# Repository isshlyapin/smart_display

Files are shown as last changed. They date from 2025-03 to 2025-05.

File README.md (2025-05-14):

# Ретрофутуристический дисплей

**Год реализации**: 2025  
**Авторы**:  
- Шляпин Илья (Б01-307) 
- Уткин Павел (Б01-307)

## Описание проекта

Проект представляет собой компактный LED-дисплей с микроконтроллером ESP32, выполненный в стиле ретрофутуризма. Устройство отображает полезную информацию (время, температура и др.), подключается по Wi-Fi и Bluetooth, поддерживает настройку яркости, цветовой гаммы и шаблонов.

Основная цель проекта — снизить информационную перегрузку пользователя, предоставляя важные данные без использования телефона или компьютера.

## Используемые компоненты

- LED матрица 64×32
- Микроконтроллер ESP32
- Датчик температуры и влажности (например, DHT11/22 или аналог)
- Блок питания (адаптер или трансформатор)
- Печатная плата (самодельная, фрезерованная)
- 3D-печатный корпус

## Технологии и инструменты

- Arduino (прошивка ESP32)
- КОМПАС-3D (проектирование корпуса)
- 3D-принтер
- GitHub (хранение кода и макетов)
- C++ (при необходимости визуализации/обработки)
- QR-код генератор для GitHub-ссылки

## Установка и запуск

1. Склонируйте репозиторий:
   ```bash
   git clone https://github.com/your_username/smart_display.git
   ```
2. Загрузите прошивку на ESP32 через Arduino IDE.
3. Подключите устройство к Wi-Fi
4. Дисплей автоматически начнет отображение.

## Сборка устройства

Для правильного подключения LED-матрицы 64×32 к микроконтроллеру ESP32, используйте следующие GPIO пины на плате:

- **GPIO 22** — Красный верхний (R1)
- **GPIO 23** — Зелёный верхний (G1)
- **GPIO 21** — Синий верхний (B1)
- **GPIO 19** — Красный нижний (R2)
- **GPIO 18** — Зелёный нижний (G2)
- **GPIO 26** — Синий нижний (B2)

Адресные линии:
- **GPIO 25** — Линия A
- **GPIO 17** — Линия B
- **GPIO 33** — Линия C
- **GPIO 16** — Линия D
- **GPIO -1** — Линия E (не используется в 64×32 панелях, только для 64×64 панелей)

Дополнительные пины для управления:
- **GPIO 4** — Latch
- **GPIO 14** — Output Enable (OE)
- **GPIO 32** — Clock (CLK)

Эти пины нужно использовать при подключении LED-матрицы к ESP32. Убедитесь, что все соединения выполнены правильно перед загрузкой прошивки.

- Спаяйте все элементы на фрезерованной плате.
- Распечатайте корпус и соберите устройство.
- Поместите все внутрь корпуса и подключите питание.

## 3D-модели

Файлы для 3D-печати (корпус, крышка) находятся в папке [`models/`](./models).  

## Функционал

- Отображение:
  - Время, дата
  - Температура и влажность
  - Пользовательские шаблоны
- Поддержка:
  - Wi-Fi, Bluetooth
  - Изменение цветовой темы
  - Настройка яркости
  - Смена часового пояса
- Расширяемость:
  - Открытый код для добавления собственных шаблонов

<video src="https://github.com/user-attachments/assets/2ec28b51-bb7a-4958-b808-4877aee1a16a" width="480px"> 
</video>

## Результаты тестирования

- Работа устройства стабильна в течение 24+ часов
- Все функции работают корректно

## QR-код на репозиторий



---

## Структура репозитория

```
smart_display/
│
├── firmware/           # Прошивка ESP32 
├── models/             # 3D-модели корпуса
├── README.md
```

---

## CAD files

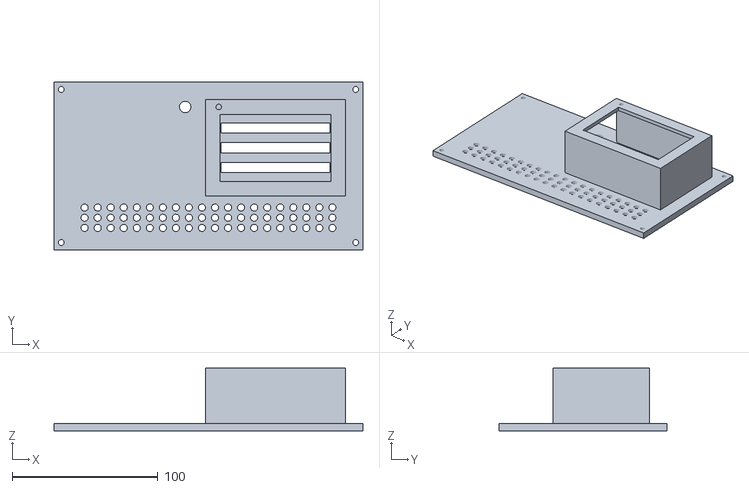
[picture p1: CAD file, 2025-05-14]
models/back_desk_smart_display.stl
212.0 x 115.0 x 43.0

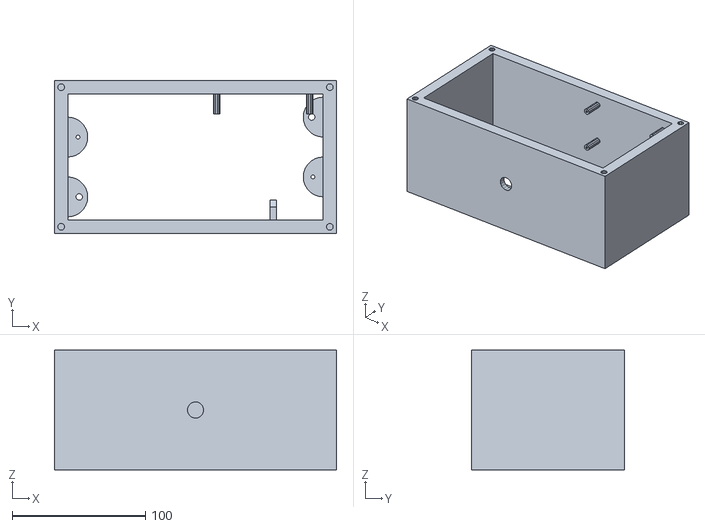
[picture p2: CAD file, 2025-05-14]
models/box_smart_display.stl
212.0 x 115.0 x 90.0

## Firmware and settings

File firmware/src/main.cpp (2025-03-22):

#include <Arduino.h>
#include <ESP32-HUB75-MatrixPanel-I2S-DMA.h>

#include "config.h"
#include "wifi_controller.h"
#include "bluetooth_controller.h"
#include "temperature_controller.h"
#include "time_controller.h"
#include "display.h"

DisplayController& displayController = DisplayController::getInstance();
MatrixPanel_I2S_DMA *display = nullptr;

// Обновление яркости дисплея
void updateBrightness() {
    static int lastBrightness = -1;
    int currentBrightness = displayController.getBrightness();
    
    if (lastBrightness != currentBrightness) {
        display->setBrightness8(currentBrightness);
        lastBrightness = currentBrightness;
    }
}

// Обновление отображаемого изображения
void updateImage() {
    static ImageType lastImage = ImageType::NOT_IMAGE;
    ImageType currentImage = displayController.getImage();
    
    if (lastImage != currentImage) {
        Serial.println("Changing image");
        Serial.printf("Current image: %d\n", currentImage);
        
        display->clearScreen();
        image_draws[currentImage](display, true);
        lastImage = currentImage;
    }
    
    image_draws[currentImage](display, false);
}

void setup() {
    Serial.begin(115200);
    
    // Инициализация дисплея
    displayController.begin();
    display = displayController.getDisplay();
    display->setBrightness8(displayController.getBrightness());

    // Создание задач для Bluetooth и WiFi
    xTaskCreate(bluetoothSetup, "bluetoothSetup", TASK_STACK_SIZE, nullptr, 1, nullptr);
    xTaskCreate(wifiSetup, "wifiSetup", TASK_STACK_SIZE, nullptr, 1, nullptr);

    // Ожидание подключения к WiFi
    while (!isWifiConnected()) {
        vTaskDelay(WIFI_CHECK_DELAY / portTICK_PERIOD_MS);
    }

    timeSetup();
}

void loop() {
    Serial.printf("Free heap loop: %d\n", ESP.getFreeHeap());
    updateBrightness();
    updateImage();
    vTaskDelay(MAIN_LOOP_DELAY / portTICK_PERIOD_MS);
}

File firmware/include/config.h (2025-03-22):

#pragma once

#include <DHT.h>

#define DHT_PIN 21
#define DHT_TYPE DHT22

static String BT_NAME = "Smart Display SIUP";

static const char* TYPE_MSG_WIFI       = "wifi";
static const char* TYPE_MSG_BRIGHTNESS = "brightness";
static const char* TYPE_MSG_IMAGE      = "image";
static const char* TYPE_MSG_TIME       = "time";
static const char* TYPE_MSG_COLOR      = "color";

// Константы для временных интервалов (в миллисекундах)
constexpr static uint32_t WIFI_CHECK_DELAY      = 500;
constexpr static uint32_t BLUETOOTH_CHECK_DELAY = 250;

constexpr static uint32_t MAIN_LOOP_DELAY = 50;

constexpr static uint32_t TASK_STACK_SIZE = 4096;

constexpr static uint32_t ANIMATION_DELAY_QUICK = 5;
constexpr static uint32_t ANIMATION_DELAY       = 40;

//Цвет по умолчанию
static const int DEFAULT_COLOR_R = 204;
static const int DEFAULT_COLOR_G = 187;
static const int DEFAULT_COLOR_B = 152;

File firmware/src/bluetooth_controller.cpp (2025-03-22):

#include <BluetoothSerial.h>
#include <ArduinoNvs.h>
#include <ArduinoJson.h>
#include <string.h>

#include "config.h"
#include "display.h"
#include "bluetooth_controller.h"
#include "time_controller.h"

static void wifiMsgHandler(JsonDocument& jsonMsg);
static void timeMsgHandler(JsonDocument& jsonMsg);
static void brightnessMsgHandler(JsonDocument& jsonMsg);
static void imageMsgHandler(JsonDocument& jsonMsg);

static void wifiMsgHandler(JsonDocument& jsonMsg) {
    const char* ssid = jsonMsg["ssid"];
    const char* password = jsonMsg["password"];
    if (ssid && password) {
        if (NVS.begin()) {
            Serial.println("wifiMsgHandler: NVS opened");
            NVS.setString("wifi_ssid", ssid);
            NVS.setString("wifi_password", password);
            NVS.close();
        } else {
            Serial.println("wifiMsgHandler: Error opening NVS");
        }
    }
}

static void timeMsgHandler(JsonDocument& jsonMsg) {
    const char* timezone = jsonMsg["timezone"];
    if (timezone) {
        if (NVS.begin()) {
            Serial.println("timeMsgHandler: NVS opened");
            NVS.setString("timezone", timezone);
            NVS.close();
        } else {
            Serial.println("timeMsgHandler: Error opening NVS");
        }
        configTime(atoi(timezone) * 3600, 0, "pool.ntp.org", "time.nist.gov");
    }
}

static void brightnessMsgHandler(JsonDocument& jsonMsg) {
    const char* value = jsonMsg["value"];
    if (value) {
        if (NVS.begin()) {
            Serial.println("brightnessMsgHandler: NVS opened");
            NVS.setInt("brightness", atoi(value));
            NVS.close();
        } else {
            Serial.println("brightnessMsgHandler: Error opening NVS");
        }
        DisplayController& displayController = DisplayController::getInstance();
        displayController.setBrightness(atoi(value));
    }
}

static void imageMsgHandler(JsonDocument& jsonMsg) {
    const char* tmp = jsonMsg["value"];
    if (tmp) {
        int value = atoi(tmp);
        DisplayController& displayController = DisplayController::getInstance();
        if (value == ImageType::CLOCK_IMAGE) {
            displayController.setImage(ImageType::CLOCK_IMAGE);
        } else if (value == ImageType::DHT_IMAGE) {
            displayController.setImage(ImageType::DHT_IMAGE);
        } else if (value == ImageType::BEAUTIFUL_CLOCK_IMAGE) {
            displayController.setImage(ImageType::BEAUTIFUL_CLOCK_IMAGE);
        }
    }
}

static void colorMsgHandler(JsonDocument& jsonMsg) {
    const char* r = jsonMsg["r"];
    const char* g = jsonMsg["g"];
    const char* b = jsonMsg["b"];
    if (r && g && b) {
        if (atoi(r) < 0 || atoi(r) > 255 || atoi(g) < 0 || atoi(g) > 255 || atoi(b) < 0 || atoi(b) > 255) {
            Serial.println("colorMsgHandler: Invalid color");
            return;
        }
        if (NVS.begin()) {
            Serial.println("colorMsgHandler: NVS opened");
            NVS.setInt("color_r", atoi(r));
            NVS.setInt("color_g", atoi(g));
            NVS.setInt("color_b", atoi(b));
            NVS.close();
        } else {
            Serial.println("colorMsgHandler: Error opening NVS");
        }
        DisplayController& displayController = DisplayController::getInstance();
        displayController.setColor(atoi(r), atoi(g), atoi(b));
    } else {
        Serial.println("colorMsgHandler: Invalid message");
    }
}

void bluetoothSetup(void* pvParameters) {
    BluetoothSerial SerialBT;
    SerialBT.begin(BT_NAME);
    while (1) {
        if (SerialBT.available()) {
            Serial.printf("Free heap bluetooth1: %d\n", ESP.getFreeHeap());
            Serial.println("Bluetooth message");
            String strMsg = SerialBT.readString();
            Serial.printf("Message: [%s]\n", strMsg.c_str());
            JsonDocument jsonMsg;
            Serial.printf("Free heap bluetooth2: %d\n", ESP.getFreeHeap());
            DeserializationError error =  deserializeJson(jsonMsg, strMsg);

            if (!error) {
                const char* type = jsonMsg["type"];
                Serial.printf("Type: [%s]\n", type);
                if (type) {
                    if (strcmp(type, TYPE_MSG_WIFI) == 0) {
                        Serial.println("Wifi message");
                        wifiMsgHandler(jsonMsg);
                    } else if (strcmp(type, TYPE_MSG_TIME) == 0) {
                        Serial.println("Time message");
                        timeMsgHandler(jsonMsg);
                    } else if (strcmp(type, TYPE_MSG_BRIGHTNESS) == 0) {
                        Serial.println("Brightness message");
                        brightnessMsgHandler(jsonMsg);
                    } else if (strcmp(type, TYPE_MSG_IMAGE) == 0) {
                        Serial.println("Image message");
                        imageMsgHandler(jsonMsg);
                    } else if (strcmp(type, TYPE_MSG_COLOR) == 0) {
                        Serial.println("Color message");
                        colorMsgHandler(jsonMsg);
                    }
                }   
            } else {
                Serial.printf("Error: %s\n", error.c_str());
            }
            strMsg.clear();
            jsonMsg.clear();
        }
        vTaskDelay(BLUETOOTH_CHECK_DELAY / portTICK_PERIOD_MS);
    }
}

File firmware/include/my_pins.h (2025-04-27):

#pragma once

#include <ESP32-HUB75-MatrixPanel-I2S-DMA.h>

#define R1_PIN 22
#define G1_PIN 23
#define B1_PIN 21
#define R2_PIN 19
#define G2_PIN 18
#define B2_PIN 26
#define A_PIN 25
#define B_PIN 17
#define C_PIN 33
#define D_PIN 16
#define E_PIN -1 // required for 1/32 scan panels, like 64x64px. Any available pin would do, i.e. IO32
#define LAT_PIN 4
#define OE_PIN 14
#define CLK_PIN 32

static HUB75_I2S_CFG::i2s_pins my_pins={R1_PIN, G1_PIN, B1_PIN, R2_PIN, G2_PIN, B2_PIN, A_PIN, B_PIN, C_PIN, D_PIN, E_PIN, LAT_PIN, OE_PIN, CLK_PIN};

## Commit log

2025-03-22 Add saving brightness at reboot esp32 + refactoring
    [bluetooth_controller.cpp, config.h, main.cpp]
2025-05-14 add directories
    [partitions.csv]
2025-05-14 add models of smart box
    [back_desk_smart_display.stl, box_smart_display.stl]
2025-05-14 upload plate
